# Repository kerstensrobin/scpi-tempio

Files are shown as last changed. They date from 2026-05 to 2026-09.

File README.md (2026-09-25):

# Nacho.works SCPI-TempIO

> USB-connected environmental sensor and GPIO control module based on the STM32G0B1KBTx.

> [!WARNING]
> **Hardware v0.01 is not ready for production.** The board must be revised before another batch is ordered. Open issues:
>
> 1. **J1 VTref is on VBUS (5 V) on the PCB.** The schematic was corrected (VTref to 3V3), but the PCB was never updated from it. With 5 V on VTref, a programmer that sets its I/O level from VTref (such as a genuine ST-Link) may drive SWD at 5 V into a 3.3 V MCU. Existing boards need a bodge: cut J1 pin 1 from VBUS and wire it to 3V3.
> 2. **The schematic hotfix also moved C7** (1 µF, the AP2112K input capacitor) from VBUS to 3V3. It must go back on VBUS before the PCB is updated from the schematic, or the regulator loses its input capacitor.
> 3. **U1 symbol still named STM32G070KBTx** in the schematic's symbol cache; the fitted part is the STM32G0B1KBT6.
> 4. **Gerbers in `hardware/production/` are from v0.01** and contain issue 1. Regenerate them after the fixes.
>
> Before ordering: fix the above, update the PCB from the schematic, run DRC with schematic parity, and check that J1 pin 1 is on 3V3 and C7 on VBUS.

---

## Repository Contents

| Path | Contents |
| --- | --- |
| `hardware/` | KiCad project `SCPI_tempIO` (board with rounded tracks), `production/` holds the v0.01 JLC outputs |
| `firmware/` | STM32CubeMX + CMake project, TinyUSB submodule in `firmware/lib/tinyusb` |
| `examples/` | Host-side example scripts (`tempio_demo.py` runs every command) |

---

## Overview

This module is a small USB-connected development and test interface based on the STM32G0B1KBTx microcontroller.

It provides:

* USB serial SCPI interface
* Temperature measurement
* Humidity measurement
* 8 configurable GPIO pins
* I2C expansion connectors
* Breadboard-friendly operation
* SWD programming/debug interface

The module is intended for:

* breadboard prototyping
* embedded testing
* automation experiments
* SCPI/VISA software integration
* GPIO scripting from a PC

---

## Features

## Environmental sensing

Integrated sensor:

* SHT41 temperature + humidity sensor (I2C1, address 0x44)

Typical measurements:

| Parameter | Typical Accuracy |
| --- | --- |
| Temperature | ±0.2 °C |
| Humidity | ±1.8 %RH |

---

## USB interface

The module connects to a host PC through USB-C and shows up as two interfaces at once. Both run the same SCPI commands and share one error queue:

| Interface | Use it for |
| --- | --- |
| USBTMC (USB488) | VISA / instrument software: `USB0::0x1209::0x0001::<serial>::INSTR` |
| CDC serial port | Terminals, pyserial, anything without VISA; no driver needed |

USB identification:

| Field | Value |
| --- | --- |
| VID:PID | 1209:0001 (pid.codes test ID, dev only) |
| Manufacturer | Nacho.works |
| Product | SCPI-TempIO v01 |
| Serial | 96-bit MCU unique ID, 24 hex characters |

The device appears as:

* COMx on Windows
* /dev/ttyACMx on Linux, also as `/dev/serial/by-id/usb-Nacho.works_SCPI-TempIO_v01_<serial>-if00`
* /dev/cu.usbmodem* on macOS

It is a native USB device, so the baud rate and other serial settings are ignored; any value works.

## VISA (USBTMC)

VISA resource string:

```text
USB0::0x1209::0x0001::<serial>::INSTR
```

The serial is the one returned by `*IDN?`. Some tools print the IDs in decimal: `USB0::4617::1::<serial>::0::INSTR` is the same instrument.

What USBTMC adds over the serial port:

* Found by VID/PID/serial, independent of COM port or ttyACM numbering
* Explicit message boundaries, no line-termination guessing
* Device clear (`viClear`): drops a half-sent command and any unread response
* Status byte (`viReadSTB`): bit 4 MAV = response waiting, bit 2 EAV = error queue not empty
* Indicator pulse ("identify" in NI MAX): the LED blinks fast for 2 s

Host setup:

* **Windows / macOS:** install NI-VISA or Keysight IO Libraries, they include the USBTMC driver.
* **Linux:** works with pyvisa + pyvisa-py (`pip install pyvisa pyvisa-py pyusb`). Install the udev rule once so a normal user can open the device and the kernel `usbtmc` driver does not claim it:

  ```sh
  sudo cp examples/99-scpi-tempio.rules /etc/udev/rules.d/
  sudo udevadm control --reload
  ```

  Then replug the unit. Without the rule, pyvisa lists the device but fails with `Resource busy`.

pyvisa-py (0.8) implements read/write/query on USB, but not `read_stb()` or `clear()`; those need NI-VISA or Keysight VISA. The firmware supports both.

The USBTMC interface is deliberately interface 0: pyvisa-py detaches the kernel driver from interface 0 when it opens a USB instrument, and would otherwise disconnect the serial port.

---

## GPIO Interface

The module exposes 8 configurable GPIO pins, DIO0–DIO7 (MCU pins PA0–PA7).

## GPIO capabilities

Each pin can be configured as:

* Digital input (default after power-up and `*RST`)
* Digital output (push-pull)
* Open-drain output
* PWM output (hardware timer, 0.1 Hz to 32 MHz)

## GPIO voltage levels

IMPORTANT:

```text
GPIO pins are 3.3V logic only.
```

Do not apply voltages above 3.3V.

## GPIO protection

Each GPIO pin includes a series protection resistor.

This improves tolerance against:

* accidental shorts
* output contention
* breadboard wiring mistakes

---

## Connector Pinout

## GPIO Header (J2)

2×5 box header, 2.54 mm pitch. Top view, pin 1 top-left:

```text
          ┌──────────────┐
  3V3   ■ 1            2 ●  DIO0
  DIO1  ● 3            4 ●  DIO2
  DIO3  ● 5            6 ●  DIO4
  DIO5  ● 7            8 ●  DIO6
  DIO7  ● 9           10 ●  GND
          └──────────────┘
```

Pin 1 (3V3) has the square pad on the bottom side and the triangle mark on the header housing. The pins alternate between the two rows: odd pins in one row, even pins in the other. DIO0 sits right next to 3V3, and GND is in the opposite corner.

| Pin | Function |
| --- | --- |
| 1 | 3V3 |
| 2 | DIO0 |
| 3 | DIO1 |
| 4 | DIO2 |
| 5 | DIO3 |
| 6 | DIO4 |
| 7 | DIO5 |
| 8 | DIO6 |
| 9 | DIO7 |
| 10  | GND |

## I2C Expansion (J4, J5)

Shared with the on-board SHT41 bus (pull-ups on board).

| Pin | Function |
| --- | --- |
| 1 | 3V3 |
| 2 | SCL |
| 3 | SDA |
| 4 | GND |

---

## SCPI Command Interface

## General

Commands are ASCII text terminated by `\n` or `\r\n`. Responses end with `\n`.

Headers are case-insensitive and accept both the short and the long form, for example `MEAS:TEMP?` and `measure:temperature?` are the same query.

Several commands can be sent on one line, separated by `;`. Each command must be written out in full (`MEAS:TEMP?;MEAS:HUM?`); the responses come back on one line, also separated by `;`.

Examples:

```text
*IDN?
MEAS:TEMP?
DIG:PIN0 1
```

---

## Supported Commands

| Command | Description |
| --- | --- |
| `*IDN?` | Identification |
| `*RST` | Reset: all GPIO pins back to input |
| `*CLS` | Clear the error queue |
| `*OPC?` | Always returns `1` |
| `*TST?` | Self test: `0` = SHT41 found, `1` = not found |
| `SYSTem:ERRor[:NEXT]?` | Read and remove the oldest error |
| `SYSTem:VERSion?` | SCPI version, `1999.0` |
| `MEASure:TEMPerature?` | Temperature in °C |
| `MEASure:HUMidity?` | Relative humidity in %RH |
| `MEASure:ALL?` | `temperature,humidity` |
| `DIGital:PIN<n>:MODE IN\|OUT\|OD` | Set pin mode |
| `DIGital:PIN<n>:MODE?` | Read pin mode |
| `DIGital:PIN<n> 0\|1\|OFF\|ON` | Set output level |
| `DIGital:PIN<n>?` | Read pin level |
| `DIGital:PIN<n>:PWM <freq>[,<duty>]` | Start PWM output |
| `DIGital:PIN<n>:PWM?` | Actual frequency and duty |
| `DIGital:PORT?` | Read all 8 pins |

`<n>` is 0–7.

---

## Identification

### Query device identification

```text
*IDN?
```

Example response:

```text
Nacho.works,SCPI-TempIO v01,2038393741565017002D005E,0.3
```

Format:

```text
MANUFACTURER,MODEL,SERIAL,FIRMWARE_VERSION
```

---

# Environmental Measurements

Every query starts a new high-precision measurement (~10 ms).

If the sensor does not respond, the value is returned as `9.91E37` (SCPI "not a number") and error `-240` is queued.

## Temperature measurement

```text
MEAS:TEMP?
```

Example response:

```text
23.41
```

Units:

```text
°C
```

---

## Humidity measurement

```text
MEAS:HUM?
```

Example response:

```text
45.72
```

Units:

```text
%RH
```

---

## Combined measurement

```text
MEAS:ALL?
```

Example response:

```text
23.41,45.72
```

Format:

```text
TEMPERATURE,HUMIDITY
```

Both values come from the same measurement.

---

# GPIO Commands

## Configure GPIO mode

### Input mode

```text
DIG:PIN0:MODE IN
```

### Output mode

```text
DIG:PIN0:MODE OUT
```

### Open-drain mode

```text
DIG:PIN0:MODE OD
```

### Read mode

```text
DIG:PIN0:MODE?
```

Example response:

```text
OUT
```

---

## Set GPIO output state

### Set HIGH

```text
DIG:PIN0 1
```

### Set LOW

```text
DIG:PIN0 0
```

The level is remembered while a pin is an input, and is applied when the pin is switched to OUT or OD. This lets you set the level first and then enable the output without a glitch.

---

## Read GPIO state

```text
DIG:PIN0?
```

Example response:

```text
1
```

This reads the actual pin level, in every mode.

---

## PWM output

Each DIO pin can output a hardware PWM signal, generated by a timer in the MCU. It is exact and jitter-free, and keeps running without further USB traffic.

```text
DIG:PIN0:PWM 1000          1 kHz, 50 % duty
DIG:PIN0:PWM 2.5MHZ,25     2.5 MHz, 25 % duty
DIG:PIN4:PWM 0.5,10%       0.5 Hz, 10 % duty
DIG:PIN0:PWM?              actual frequency,duty, e.g. 1000,50
DIG:PIN0:MODE OUT          stop PWM, back to normal output
```

* Frequency: 0.1 Hz to 32 MHz, as a plain number in Hz or with `HZ`, `KHZ` or `MHZ` (SCPI `MHZ` is megahertz).
* Duty: 0 to 100 %, default 50 %.
* `DIG:PIN<n>:MODE?` returns `PWM` while PWM is running. `DIG:PIN<n>:MODE IN|OUT|OD` or `*RST` stops it.
* The timer rounds to the nearest reachable setting; `DIG:PIN<n>:PWM?` returns what is actually generated. At high frequencies the duty resolution gets coarse: at 32 MHz only 0, 50 and 100 % are possible.
* Signal quality: the 330 Ω series resistor and the probe or cable capacitance round the edges. Expect a clean square wave up to roughly 5–10 MHz.

Pins that share a timer also share the frequency:

| Timer | Pins | Shared |
| ----- | --- | --- |
| TIM2  | DIO0, DIO1, DIO5 | Frequency; DIO0 and DIO5 also share the duty (same channel) |
| TIM15 | DIO2, DIO3 | Frequency |
| TIM14 | DIO4 | — |
| TIM16 | DIO6 | — |
| TIM17 | DIO7 | — |

Setting a different frequency on a pin whose timer is already in use gives error `-221`; stop the other pin first or use the same frequency.

---

## Read all GPIO states

```text
DIG:PORT?
```

Example response:

```text
10100110
```

The first character is DIO7 and the last is DIO0. In the example above, DIO1, DIO2, DIO5 and DIO7 are high.

---

## Errors

Errors are queued (up to 8) and read one at a time with `SYST:ERR?`. `0,"No error"` means the queue is empty.

| Code | Meaning |
| ---- | --- |
| -108 | Parameter not allowed |
| -109 | Missing parameter |
| -113 | Undefined header (unknown command) |
| -114 | Header suffix out of range (pin number not 0–7) |
| -120 | Numeric data error (number expected) |
| -131 | Invalid suffix (unit other than HZ, KHZ, MHZ) |
| -221 | Settings conflict (PWM timer shared with another pin) |
| -222 | Data out of range (PWM frequency or duty) |
| -223 | Too much data (response line too long) |
| -224 | Illegal parameter value |
| -240 | Hardware error (SHT41 not responding) |
| -350 | Queue overflow |
| -363 | Input buffer overrun (command line over 127 characters) |

---

## Status LED

| LED | Meaning |
| --- | --- |
| Blinking (2 Hz) | Not enumerated by a USB host |
| On | Enumerated, ready |
| Short off-flick | A command was received |
| Fast blink (2 s)  | Identify request (USBTMC indicator pulse) |

---

## Programming and Debugging

## SWD Interface (J1)

The module includes a 10-pin 1.27 mm Cortex debug connector.

Signals:

| Signal | Description |
| --- | --- |
| SWDIO  | Debug data |
| SWCLK  | Debug clock |
| NRST | Reset |
| VTref  | Target voltage |
| GND | Ground |

Compatible programmers:

* ST-Link V2
* ST-Link V3

Notes:

* The SWD cable does not power the board. Power it from USB.
* With a Treedix JTAG/SWD adapter board, install the VCC→VREF jumper. Otherwise the ST-Link reads about 1.7 V (floating VTref) and will not connect.
* On v0.01 boards, VTref (J1 pin 1) is routed to VBUS (5 V) instead of 3V3; see the warning at the top. Unless the board has been bodged, the ST-Link reports about 5 V target voltage and may drive SWD at that level. Bodge J1 pin 1 to 3V3 before connecting a programmer, or flash a blank board over USB DFU instead.
* Put the scope or multimeter ground on J2 pin 10 (GND), never on pin 1 (3V3). A bench scope's ground is mains earth, which the PC's USB ground is also tied to, so clipping it onto 3V3 shorts the regulator output. On one v0.01 board this destroyed U2 (AP2112K), leaving the MCU running on 5 V.

---

## Firmware Development

Toolchain:

* STM32CubeMX for pin and clock configuration (`firmware/tempio.ioc`, toolchain set to CMake)
* CMake + arm-none-eabi-gcc (the one bundled with STM32CubeIDE works)
* STM32 HAL
* TinyUSB 0.21.0 (git submodule in `firmware/lib/tinyusb`)
* STM32CubeProgrammer CLI or any SWD tool for flashing

Source layout:

| Path | Contents |
| --- | --- |
| `firmware/App/` | Application code (SCPI, SHT41, DIO, USB CDC + USBTMC) |
| `firmware/App/Inc/version.h` | Manufacturer, model and firmware version |
| `firmware/Src`, `firmware/Inc` | CubeMX generated code |

Application code lives in `App/` and is called from `main.c` inside the `USER CODE` sections, so regenerating from CubeMX keeps it.

USB is deliberately left disabled in CubeMX. TinyUSB drives the peripheral, and `App/Src/usb_hw.c` sets up the USB clock (HSI48 trimmed by the CRS, no crystal needed) and the interrupt handler.

## Build

```sh
git submodule update --init
cd firmware
cmake -S . -B build/Debug -G "Unix Makefiles" \
      -DCMAKE_TOOLCHAIN_FILE=cmake/gcc-arm-none-eabi.cmake -DCMAKE_BUILD_TYPE=Debug
cmake --build build/Debug
```

`arm-none-eabi-gcc` must be on the `PATH`. With Ninja installed, `cmake --preset Debug` also works.

## Flash

```sh
STM32_Programmer_CLI -c port=SWD mode=UR -w build/Debug/tempio.elf -v -rst
```

---

## Electrical Specifications

| Parameter | Value |
| --- | --- |
| USB input voltage  | 5V |
| Logic voltage | 3.3V |
| GPIO voltage range | 0–3.3V |
| GPIO direction | Configurable  |
| MCU | STM32G0B1KBTx |
| Sensor | SHT41 |

---

## Safety Notes

## IMPORTANT

Do not:

* connect GPIO pins directly to mains voltage
* exceed 3.3V on GPIO pins
* drive motors directly from GPIO pins
* short outputs together intentionally

For inductive loads:

* use transistors or MOSFETs
* use flyback diodes

---

## Example Python Usage

`examples/tempio_demo.py` connects to the unit and runs every command once:

```sh
pip install pyserial
python3 examples/tempio_demo.py            # auto-detect on Linux/macOS
python3 examples/tempio_demo.py COM5       # or give the port
```

Minimal VISA version:

```python
import pyvisa

rm = pyvisa.ResourceManager()          # '@py' for pyvisa-py
print(rm.list_resources())

inst = rm.open_resource('USB0::0x1209::0x0001::2038393741565017002D005E::INSTR')
print(inst.query('*IDN?'))
print(inst.query('MEAS:ALL?'))
inst.write('DIG:PIN0:MODE OUT')
inst.write('DIG:PIN0 1')
```

Minimal serial version:

```python
import serial

s = serial.Serial('/dev/ttyACM0', timeout=1)

s.write(b'*IDN?\n')
print(s.readline().decode())

s.write(b'MEAS:TEMP?\n')
print(s.readline().decode())

s.write(b'DIG:PIN0:MODE OUT\n')
s.write(b'DIG:PIN0 1\n')
```

---

## Revision

| Revision | Description |
| --- | --- |
| 1.0 | Initial draft |
| 1.1 | Firmware 0.1: USB CDC SCPI, SHT41, GPIO; MCU corrected to STM32G0B1 |
| 1.2 | Firmware 0.2: added USBTMC/USB488 interface (VISA) next to CDC |
| 1.3 | Firmware 0.3: PWM output on all DIO pins; hardware v0.01 production warning |

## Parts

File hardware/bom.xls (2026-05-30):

Comment | Designator | Footprint | JLCPCB Part # | Qty | Ext.Price($)
LED | D1 | 0402 | C965793 | 20 | 0.16
SW_SPST | SW1 | SW_Push_1P1T_NO_CK_KSC7xxJ | C10852 | 5 | 0.11
AP2112K-3.3 | U2 | SOT-23-5 | C23380830 | 5 | 0.54
SHT4x | U3 | Sensirion_DFN-4_1.5x1.5mm_P0.8mm_SHT4x_NoCentralPad | C54946589 | 2 | 1.92
1u | C7 | 0805 | C28323 | 2 | 0.04
330 | R14,R15,R16,R17,R18,R19,R20,R21 | 0402 | C25104 | 16 | 0.02
USB_C_Receptacle_USB2.0_16P | J3 | USB_C_Receptacle_G-Switch_GT-USB-7025 | C963213 | 2 | 1.35
1000 | R9 | 0402 | C11702 | 2 | 0.00
100n | C5,C6,C9 | 0805 | C49678 | 6 | 0.04
5.1k | R10,R11 | 0402 | C25905 | 4 | 0.00
10k | R23,R24 | 0402 | C25744 | 4 | 0.01
22 | R12,R13 | 0402 | C25092 | 4 | 0.00
STM32G070KBTx | U1 | LQFP-32_7x7mm_P0.8mm | C529339 | 2 | 3.61
4.7n | C8 | 0805 | C1744 | 2 | 0.01
Conn_ARM_JTAG_SWD_10 | J1 | PinHeader_2x05_P1.27mm_Vertical_SMD | C2935458 | 2 | 0.31

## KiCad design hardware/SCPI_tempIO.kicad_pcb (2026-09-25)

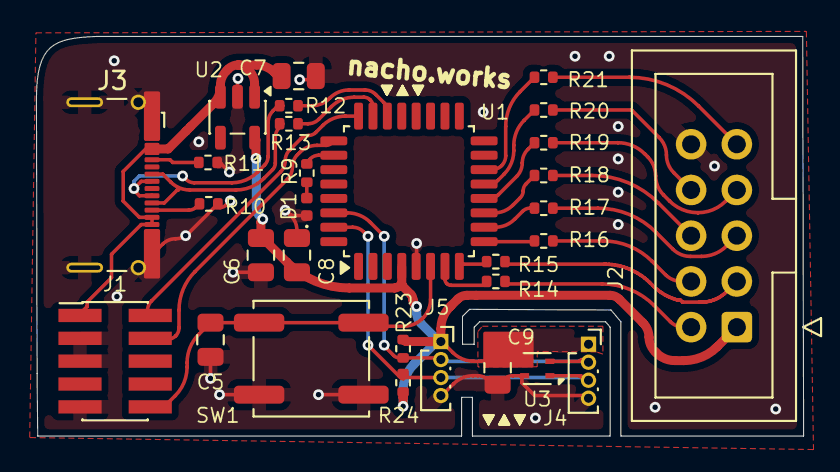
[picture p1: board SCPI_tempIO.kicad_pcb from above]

Board: 2 copper layers, 42.6 x 22.2 mm, 30 parts (0 on the bottom side), 32 nets.

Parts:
C5, C6, C9: 100n; C_0805_2012Metric
C7: 1u; C_0805_2012Metric
C8: 4.7n; C_0805_2012Metric
D1: LED; LED_0402_1005Metric
J1: Conn_ARM_JTAG_SWD_10; PinHeader_2x05_P1.27mm_Vertical_SMD
J2: Conn_02x05_Counter_Clockwise; IDC-Header_2x05_P2.54mm_Vertical
J3: USB_C_Receptacle_USB2.0_16P; USB_C_Receptacle_G-Switch_GT-USB-7025
J4, J5: Conn_01x04_Pin; PinSocket_1x04_P1.00mm_Vertical
R9: 1000; R_0402_1005Metric
R10, R11: 5.1k; R_0402_1005Metric
R12, R13: 22; R_0402_1005Metric
R14, R15, R16, R17, R18, R19, R20, R21: 330; R_0402_1005Metric
R23, R24: 10k; R_0402_1005Metric
SW1: SW_SPST; SW_Push_1P1T_NO_CK_KSC7xxJ
U1: STM32G070KBTx; LQFP-32_7x7mm_P0.8mm
U2: AP2112K-3.3; SOT-23-5
U3: SHT4x; Sensirion_DFN-4_1.5x1.5mm_P0.8mm_SHT4x_NoCentralPad

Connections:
/3v3: C6.1, C8.1, C9.1, J2.1, J4.1, J5.1, R23.1, R24.1, U1.4 (VDD), U2.5 (VOUT), U3.3 (VDD)
/SHT4x_sub/SCL: J4.2, J5.2, R23.2, U1.30 (PB6), U3.2 (SCL)
/SHT4x_sub/SDA: J4.3, J5.3, R24.2, U1.31 (PB7), U3.1 (SDA)
/USBD+: R13.2, U1.23 (PA10/PA12)
/USBD-: R12.2, U1.22 (PA9/PA11)
GND: C5.2, C6.2, C7.2, C8.2, C9.2, D1.1 (K), J1.3 (GND), J1.5 (GND), J1.9 (GNDDetect), J2.10, J3.A1 (GND), J3.A12 (GND), J3.B1 (GND), J3.B12 (GND), J3.SH (SHIELD), J4.4, J5.4, R10.2, R11.2, SW1.2 (B), U1.5 (VSS), U2.2 (GND), U3.4 (VSS)
unnamed: D1.2 (A), R9.2
unnamed: J1.4 (SWCLK/TCK), U1.25 (PA14)
unnamed: J1.2 (SWDIO/TMS), U1.24 (PA13)
unnamed: C7.1, J1.1 (VTref), J3.A4 (VBUS), J3.A9 (VBUS), J3.B4 (VBUS), J3.B9 (VBUS), U2.1 (VIN), U2.3 (EN)
unnamed: C5.1, J1.10 (~RESET), SW1.1 (A), U1.6 (NRST)
unnamed: J2.2, R14.2
unnamed: J2.3, R15.2
unnamed: J2.4, R16.2
unnamed: J2.5, R17.2
unnamed: J2.6, R18.2
unnamed: J2.7, R19.2
unnamed: J2.8, R20.2
unnamed: J2.9, R21.2
unnamed: J3.A5 (CC1), R11.1
unnamed: J3.B5 (CC2), R10.1
unnamed: J3.A6 (D+), J3.B6 (D+), R13.1
unnamed: J3.A7 (D-), J3.B7 (D-), R12.1
unnamed: R14.1, U1.7 (PA0)
unnamed: R15.1, U1.8 (PA1)
unnamed: R16.1, U1.9 (PA2)
unnamed: R17.1, U1.10 (PA3)
unnamed: R18.1, U1.11 (PA4)
unnamed: R19.1, U1.12 (PA5)
unnamed: R20.1, U1.13 (PA6)
unnamed: R21.1, U1.14 (PA7)
unnamed: R9.1, U1.26 (PA15)

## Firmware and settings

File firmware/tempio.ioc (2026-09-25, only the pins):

Mcu.UserName=STM32G0B1KBTx
PA13.Signal=SYS_SWDIO
PA14-BOOT0.Signal=SYS_SWCLK
PA15.GPIO_Label=LED
PA15.Signal=GPIO_Output
PB6.Signal=I2C1_SCL
PB7.Signal=I2C1_SDA

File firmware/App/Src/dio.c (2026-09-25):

#include "main.h"
#include "dio.h"

#define DIO_PORT GPIOA

/* Timer channel per DIO pin, from the STM32G0B1 alternate function table.
 * PA5 only has TIM2_CH1, the same channel as PA0. */
typedef struct {
  TIM_TypeDef *tim;
  uint8_t ch;
  uint8_t af;
} pwm_map_t;

static const pwm_map_t pwm_map[DIO_COUNT] = {
  {TIM2,  1, GPIO_AF2_TIM2},  /* DIO0 PA0 */
  {TIM2,  2, GPIO_AF2_TIM2},  /* DIO1 PA1 */
  {TIM15, 1, GPIO_AF5_TIM15}, /* DIO2 PA2 */
  {TIM15, 2, GPIO_AF5_TIM15}, /* DIO3 PA3 */
  {TIM14, 1, GPIO_AF4_TIM14}, /* DIO4 PA4 */
  {TIM2,  1, GPIO_AF2_TIM2},  /* DIO5 PA5 */
  {TIM16, 1, GPIO_AF5_TIM16}, /* DIO6 PA6 */
  {TIM17, 1, GPIO_AF5_TIM17}, /* DIO7 PA7 */
};

static dio_mode_t modes[DIO_COUNT];

/* ---------- timer helpers ---------- */

static uint32_t timer_clock(void)
{
  uint32_t pclk = HAL_RCC_GetPCLK1Freq();
  return (RCC->CFGR & RCC_CFGR_PPRE_2) ? 2 * pclk : pclk; /* x2 when APB is divided */
}

static void timer_clk_enable(TIM_TypeDef *t)
{
  if (t == TIM2) __HAL_RCC_TIM2_CLK_ENABLE();
  else if (t == TIM14) __HAL_RCC_TIM14_CLK_ENABLE();
  else if (t == TIM15) __HAL_RCC_TIM15_CLK_ENABLE();
  else if (t == TIM16) __HAL_RCC_TIM16_CLK_ENABLE();
  else if (t == TIM17) __HAL_RCC_TIM17_CLK_ENABLE();
}

static volatile uint32_t *ccr_reg(TIM_TypeDef *t, unsigned ch)
{
  return &t->CCR1 + (ch - 1);
}

/* Another pin (not `pin`) running PWM on the same timer, and optionally the same channel. */
static int other_pwm_user(unsigned pin, bool same_channel)
{
  for (unsigned j = 0; j < DIO_COUNT; j++) {
    if (j == pin || modes[j] != DIO_MODE_PWM || pwm_map[j].tim != pwm_map[pin].tim) continue;
    if (!same_channel || pwm_map[j].ch == pwm_map[pin].ch) return (int)j;
  }
  return -1;
}

static void channel_start(TIM_TypeDef *t, unsigned ch, uint32_t ccr)
{
  volatile uint32_t *ccmr = ch <= 2 ? &t->CCMR1 : &t->CCMR2;
  unsigned sh = ((ch - 1) & 1) * 8;
  uint32_t clear = (0x3u << sh) | (0x7u << (4 + sh)) | (1u << (16 + sh)); /* CCxS, OCxM */
  *ccmr = (*ccmr & ~clear) | (6u << (4 + sh)) | (1u << (3 + sh));         /* PWM mode 1, preload */
  *ccr_reg(t, ch) = ccr;
  t->CCER |= 1u << ((ch - 1) * 4);
}

static void channel_stop(TIM_TypeDef *t, unsigned ch)
{
  t->CCER &= ~(1u << ((ch - 1) * 4));
}

static void pwm_release(unsigned pin)
{
  const pwm_map_t *m = &pwm_map[pin];
  modes[pin] = DIO_MODE_IN; /* so other_pwm_user() no longer counts this pin */
  if (other_pwm_user(pin, true) < 0) channel_stop(m->tim, m->ch);
  if (other_pwm_user(pin, false) < 0) m->tim->CR1 &= ~TIM_CR1_CEN;
}

/* ---------- public API ---------- */

void dio_init(void)
{
  __HAL_RCC_GPIOA_CLK_ENABLE();
  for (unsigned i = 0; i < DIO_COUNT; i++) {
    HAL_GPIO_WritePin(DIO_PORT, 1u << i, GPIO_PIN_RESET);
    dio_set_mode(i, DIO_MODE_IN);
  }
}

void dio_set_mode(unsigned pin, dio_mode_t mode)
{
  if (modes[pin] == DIO_MODE_PWM) pwm_release(pin);

  GPIO_InitTypeDef init = {0};
  init.Pin = 1u << pin;
  init.Pull = GPIO_NOPULL;
  init.Speed = GPIO_SPEED_FREQ_LOW;
  switch (mode) {
    case DIO_MODE_OUT: init.Mode = GPIO_MODE_OUTPUT_PP; break;
    case DIO_MODE_OD:  init.Mode = GPIO_MODE_OUTPUT_OD; break;
    default:           init.Mode = GPIO_MODE_INPUT; mode = DIO_MODE_IN; break;
  }
  /* ODR keeps its value across mode changes, so outputs come up at the last written level. */
  HAL_GPIO_Init(DIO_PORT, &init);
  modes[pin] = mode;
}

dio_mode_t dio_get_mode(unsigned pin)
{
  return modes[pin];
}

void dio_write(unsigned pin, bool level)
{
  HAL_GPIO_WritePin(DIO_PORT, 1u << pin, level ? GPIO_PIN_SET : GPIO_PIN_RESET);
}

bool dio_read(unsigned pin)
{
  return HAL_GPIO_ReadPin(DIO_PORT, 1u << pin) == GPIO_PIN_SET;
}

uint8_t dio_read_port(void)
{
  return (uint8_t)(DIO_PORT->IDR & 0xFF);
}

dio_err_t dio_set_pwm(unsigned pin, uint64_t freq_mhz, uint32_t duty_c100)
{
  if (freq_mhz < DIO_PWM_MIN_MHZ || freq_mhz > DIO_PWM_MAX_MHZ) return DIO_ERR_RANGE;
  if (duty_c100 > DIO_PWM_DUTY_MAX) return DIO_ERR_RANGE;

  const pwm_map_t *m = &pwm_map[pin];
  TIM_TypeDef *t = m->tim;

  /* Timer counts per period, split into prescaler and auto-reload so ARR is as large as
   * possible (best duty resolution). Integer math: frequency is in millihertz. */
  uint64_t clk_mhz = (uint64_t)timer_clock() * 1000u;
  uint64_t ticks = (clk_mhz + freq_mhz / 2) / freq_mhz;
  uint64_t span = (t == TIM2) ? (1ull << 32) : (1ull << 16); /* TIM2 is 32-bit, the rest 16-bit */
  uint32_t psc = ticks > span ? (uint32_t)((ticks - 1) / span) : 0; /* ceil(ticks / span) - 1 */
  uint32_t period = (uint32_t)((ticks + (psc + 1) / 2) / (psc + 1));
  if (period < 2) period = 2;
  uint32_t arr = period - 1;
  uint32_t ccr = (uint32_t)(((uint64_t)duty_c100 * period + DIO_PWM_DUTY_MAX / 2) / DIO_PWM_DUTY_MAX);

  /* Pins sharing the timer must agree on the period; DIO0/DIO5 also on the duty. */
  if (other_pwm_user(pin, false) >= 0 && (t->PSC != psc || t->ARR != arr)) return DIO_ERR_CONFLICT;
  if (other_pwm_user(pin, true) >= 0 && *ccr_reg(t, m->ch) != ccr) return DIO_ERR_CONFLICT;

  if (other_pwm_user(pin, false) < 0) {
    /* This pin is the timer's only user: (re)program the time base. The update event comes
     * after channel_start() so the preloaded duty applies from the first period on. */
    timer_clk_enable(t);
    t->CR1 = 0;
    t->PSC = psc;
    t->ARR = arr;
    t->CR1 = TIM_CR1_ARPE;
    channel_start(t, m->ch, ccr);
    t->EGR = TIM_EGR_UG; /* load PSC, ARR and CCR now */
    if (IS_TIM_BREAK_INSTANCE(t)) t->BDTR |= TIM_BDTR_MOE;
  } else {
    /* Timer already running for another pin: the new duty takes effect at the next period. */
    channel_start(t, m->ch, ccr);
  }
  t->CR1 |= TIM_CR1_CEN;

  GPIO_InitTypeDef init = {0};
  init.Pin = 1u << pin;
  init.Mode = GPIO_MODE_AF_PP;
  init.Pull = GPIO_NOPULL;
  init.Speed = GPIO_SPEED_FREQ_VERY_HIGH;
  init.Alternate = m->af;
  HAL_GPIO_Init(DIO_PORT, &init);
  modes[pin] = DIO_MODE_PWM;
  return DIO_OK;
}

void dio_get_pwm(unsigned pin, uint64_t *freq_mhz, uint32_t *duty_c100)
{
  if (modes[pin] != DIO_MODE_PWM) {
    *freq_mhz = 0;
    *duty_c100 = 0;
    return;
  }
  const pwm_map_t *m = &pwm_map[pin];
  uint64_t period = (uint64_t)m->tim->ARR + 1u;
  uint64_t div = ((uint64_t)m->tim->PSC + 1u) * period;
  *freq_mhz = ((uint64_t)timer_clock() * 1000u + div / 2) / div;
  *duty_c100 = (uint32_t)(((uint64_t)*ccr_reg(m->tim, m->ch) * DIO_PWM_DUTY_MAX + period / 2) / period);
}

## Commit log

2026-05-26 intial dump
    [SCPI_tempIO.kicad_pcb, SCPI_tempIO.kicad_sch]
2026-05-26 USB for contemporary goodness
    [SCPI_tempIO.kicad_sch]
2026-05-26 assigned gpio r footprints
    [SCPI_tempIO.kicad_sch]
2026-05-26 PCB BABY
    [SCPI_tempIO.kicad_pcb, SCPI_tempIO.kicad_sch]
2026-05-26 more fancy
    [SCPI_tempIO.kicad_pcb]
2026-05-29 pullups and cap for the SHT4x
    [SCPI_tempIO.kicad_pcb, SCPI_tempIO.kicad_sch, SHT4x_sub.kicad_sch]
2026-05-30 sent to JLC noodleUSBp16
    [SCPI_tempIO-rounded.kicad_pcb, SCPI_tempIO.kicad_pcb, SCPI_tempIO.kicad_sch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]
2026-07-21 schematic hotfix for VTref to VDD and note about Vref to VCC jumper on treedix board.
    [SCPI_tempIO.kicad_sch, SHT4x_sub.kicad_sch]
2026-07-21 blinking led example
2026-09-25 Firmware 0.1: USB CDC SCPI interface with SHT41 and GPIO
    - Move the CubeMX project to the CMake toolchain, 64 MHz PLL, I2C1 on PB6/PB7
    - Add TinyUSB 0.21.0 as submodule; USB clock from HSI48 + CRS
    - App code in STM/cubeMX/tempio/App: SCPI parser, SHT41 driver, DIO0-7,
    identifies as "Nacho.works,SCPI-TempIO v01,<UID>,0.1"
    - Add examples/tempio_demo.py that exercises every command
    - README: correct MCU, J2 pinout, full command/error reference, build/flash steps
    - Remove CubeIDE build output and project files, stop tracking .metadata
    [app.c, dio.c, scpi.c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]
2026-09-25 Restructure repo into hardware/, firmware/ and examples/
    - hardware/: KiCad project, fabrication outputs and BOM
    - firmware/: CubeMX + CMake project (was STM/cubeMX/tempio),
    TinyUSB submodule moved to firmware/lib/tinyusb
    - Remove old drafts (STM/tempio, tempioFirm.c) and the STM32G070
    datasheet, which is not the MCU on the board
    - Update README, .gitignore and .gitmodules paths
    [SCPI_tempIO-rounded.kicad_pcb, SCPI_tempIO.kicad_pcb, SCPI_tempIO.kicad_sch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]
2026-09-25 PCB: move J2 reference label beside the GPIO header
    [SCPI_tempIO-rounded.kicad_pcb]
2026-09-25 Firmware 0.2: add USBTMC/USB488 interface for VISA
    - Composite device: USBTMC (interface 0) + CDC serial, both on the same
    SCPI parser and error queue
    - VISA address USB0::0x1209::0x0001::<serial>::INSTR
    - Status byte (MAV, EAV), device clear, indicator pulse (LED identify)
    - USBTMC sits on interface 0 because pyvisa-py detaches the kernel driver
    from interface 0 on open, which would otherwise drop the serial port
    - Add udev rule for Linux: plugdev access and keep the kernel usbtmc
    driver off the interface so pyvisa-py can claim it
    - README: VISA setup per OS, pyvisa example
    [app.c, scpi.c]
2026-09-25 Hardware: make the rounded (fabricated) board the project PCB
    SCPI_tempIO-rounded.kicad_pcb replaces SCPI_tempIO.kicad_pcb, which was the
    pre-rounding board with the old HRO USB-C connector. One project now, so
    Update PCB from Schematic works. The rounded project's extra 0.1 mm track
    width is carried over; its .kicad_pro/.kicad_dru are removed.
    [SCPI_tempIO-rounded.kicad_pcb, SCPI_tempIO.kicad_pcb]
2026-09-25 Firmware 0.3: hardware PWM on all DIO pins; v0.01 production warning
    - DIG:PIN<n>:PWM <freq>[,<duty>] and DIG:PIN<n>:PWM?, 0.1 Hz to 32 MHz,
    units HZ/KHZ/MHZ, duty 0-100 %, timers TIM2/14/15/16/17
    - Pins sharing a timer must agree on frequency (-221 otherwise)
    - Fixed-point math and own number parser instead of doubles/strtod
    (+5 KB flash instead of +24 KB)
    - Duty is valid from the first period (CCR loaded before the update event)
    - README: PWM section, new error codes, warning that hardware v0.01 needs
    revision before production (VTref on VBUS in the PCB, C7 moved by the
    schematic hotfix, U1 symbol name, stale gerbers), scope ground note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
    [dio.c, scpi.c]
